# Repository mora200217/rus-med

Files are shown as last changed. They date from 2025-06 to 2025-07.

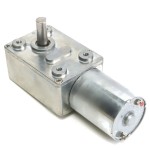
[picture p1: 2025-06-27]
sim/motor.jpeg

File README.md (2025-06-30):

# RUSMED
¡Conoce RUSMED! Una nueva herramienta para acelerar el proceso de diagnóstico de transtornos del manguito rotador 

---

## Sensores disponibles 
### IMU 
RUSMED cuenta con una unidad de medida inercial (IMU) BMI160. Publica la orientación del efector final. Esto permite una mayor escalabilidad del prototipo, al poder reconstruir el volumen analizado, a partir de la imagenes ultrasonográficas. 

### Integración con ROS2

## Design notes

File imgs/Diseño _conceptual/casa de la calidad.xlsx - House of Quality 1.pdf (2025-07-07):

Title: Sistema Robotizado para diagnóstico de TMR por US | Legend
Author: Grupo D | Θ | Strong Relationship | 9
Date: 27/4/2025 | Ο | Moderate Relationship | 3
Notes: | ▲ | Weak Relationship | 1
┼┼ | | | | | Strong Positive Correlation
┼ | Positive Correlation ▬ | Negative Correlation ▼ | Strong Negative Correlation ▼ | Objective Is To Minimize ▲ | Objective Is To Maximize
x | Objective Is To Hit Target
Column # | 1 | 2 | 3 | 4 | 5 | 6 | 7 | 8 | 9 | 10 | 11 | 12 | 13 | 14 | 15
Direction of Improvement: Minimize (▼), Maximize (▲), or Target (x) | ▼ | x | x | x | ▼ | ▲ | ▼ | x | ▲
| | | | Quality Characteristics (a.k.a. "Functional Requirements" or "Hows") Demanded Quality (a.k.a. "Customer Requirements" or "Whats")
1 | 9 | 26,3 | 10,0 | Rapidez en diagnóstico | Θ | ▲ | Ο | ▲ | ▲ | | | Ο | ▲
2 | 9 | 23,7 | 9,0 | Confiable | Θ | Ο | Θ | Θ | | | | Θ | Θ
3 | 9 | 15,8 | 6,0 | Agradable de usar | Ο | Θ | Ο | Θ | Θ | Ο | Ο | Ο
4 | 9 | 21,1 | 8,0 | Ligero para el paciente | | Ο | Θ | ▲ | Θ
5 | 3 | 13,2 | 5,0 | Fácil transporte | | ▲ | | | Ο

6

7

8

9

10

| | | | Target or Limit Value
| | | | Difficulty (0=Easy to Accomplish, 10=Extremely Difficult) | 8 | 4 | 9 | 9 | 7 | 4 | 5 | 8 | 10
| | | | Max Relationship Value in Column | 9 | 9 | 9 | 9 | 9 | 3 | 3 | 9 | 9
| | | | Weight / Importance | 497,4 | 315,8 | 528,9 | 402,6 | 397,4 | 47,4 | 47,4 | 339,5 | 239,5

Row #

Max Relationship Value in Row

Relative Weight

Weight / Importance

Tiempo de diagnóstico

Uso intuitivo de herramienta

### Ángulo de ataque transductor

Presión de contacto

Peso del Robot

Estética agradable

Ruido del mecanismo

Grado de autonomía ISO 8373

Repetibilidad

10 min
- 15 deg

1.5 - 2 kPa
50 N
- 30 dB

Nivel 3

SSIN - 0.8

Relative Weight | 17,7 | 11,2 | 18,8 | 14,3 | 14,1 | 1,7 | 1,7 | 12,1 | 8,5 | Powered by QFD Online (http://www.QFDOnline.com)

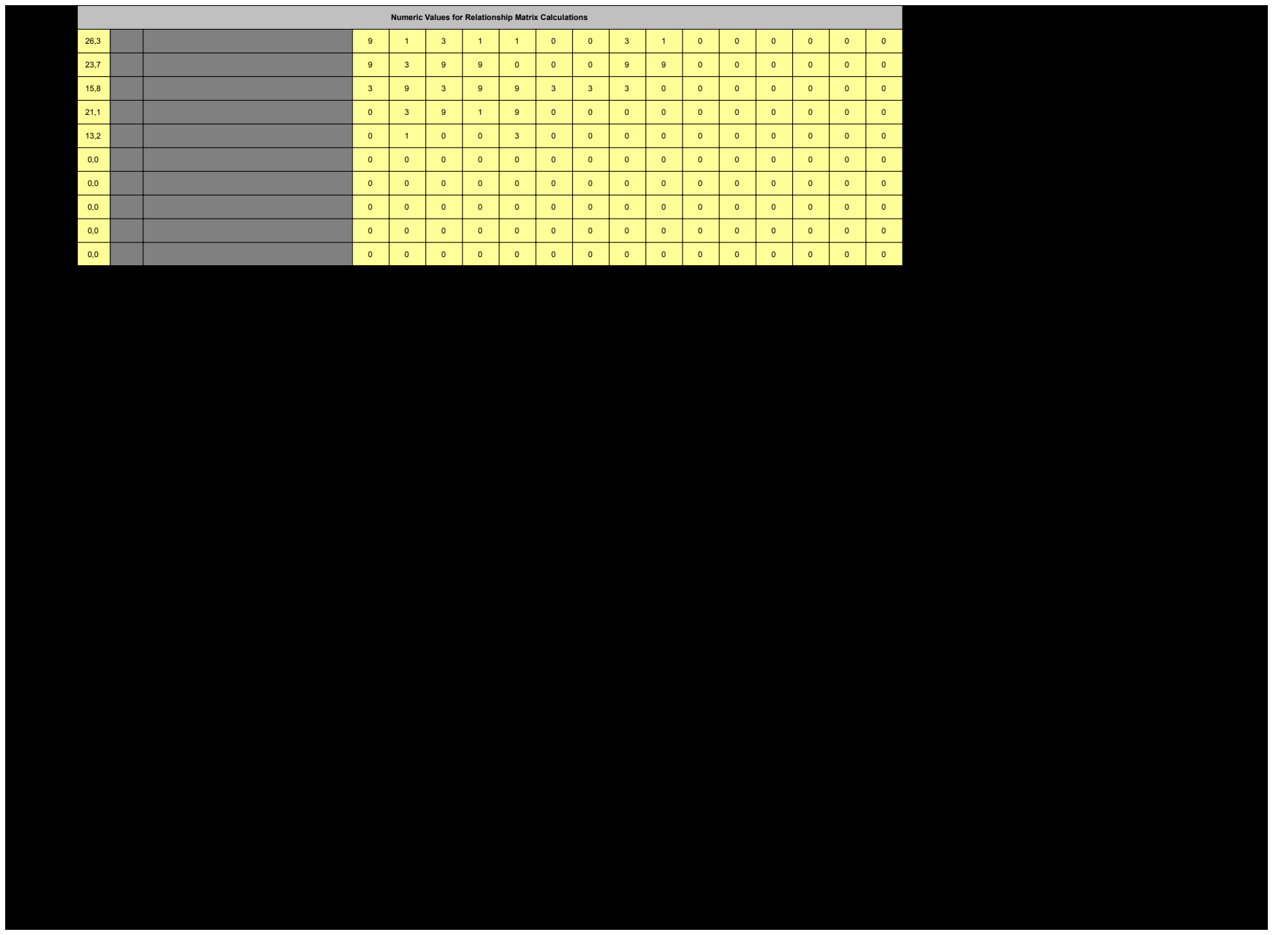
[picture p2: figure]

Numeric Values for Relationship Matrix Calculations

Chart Axis Values

0,95

0,85

0,75

0,65

0,55

0,45

0,35

0,25

0,15

0,05

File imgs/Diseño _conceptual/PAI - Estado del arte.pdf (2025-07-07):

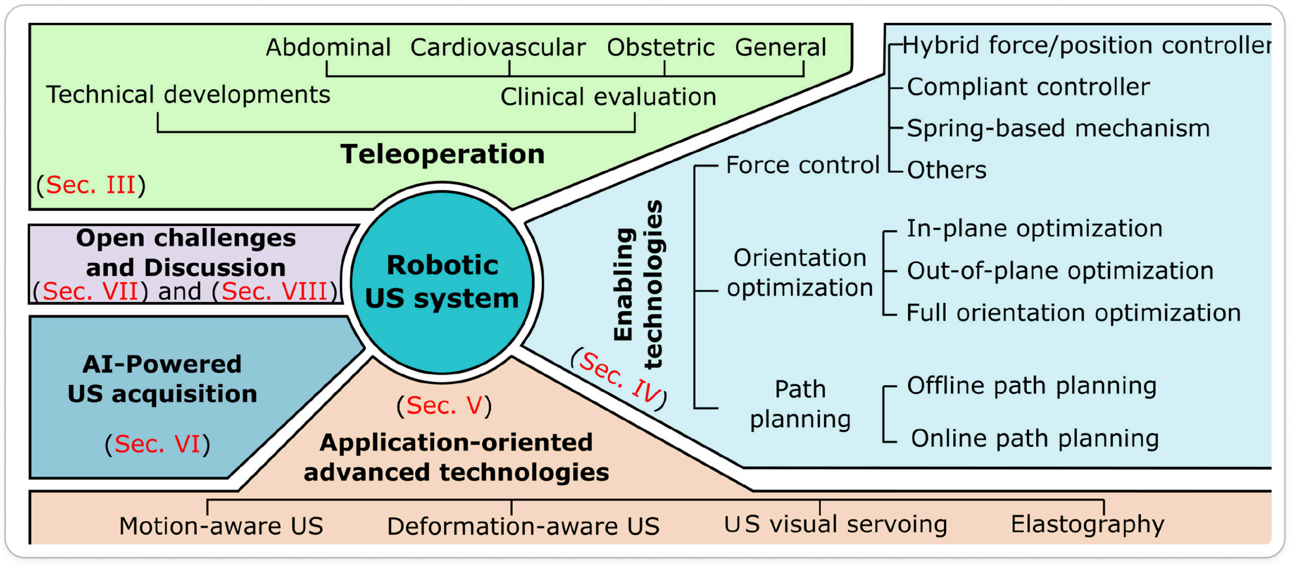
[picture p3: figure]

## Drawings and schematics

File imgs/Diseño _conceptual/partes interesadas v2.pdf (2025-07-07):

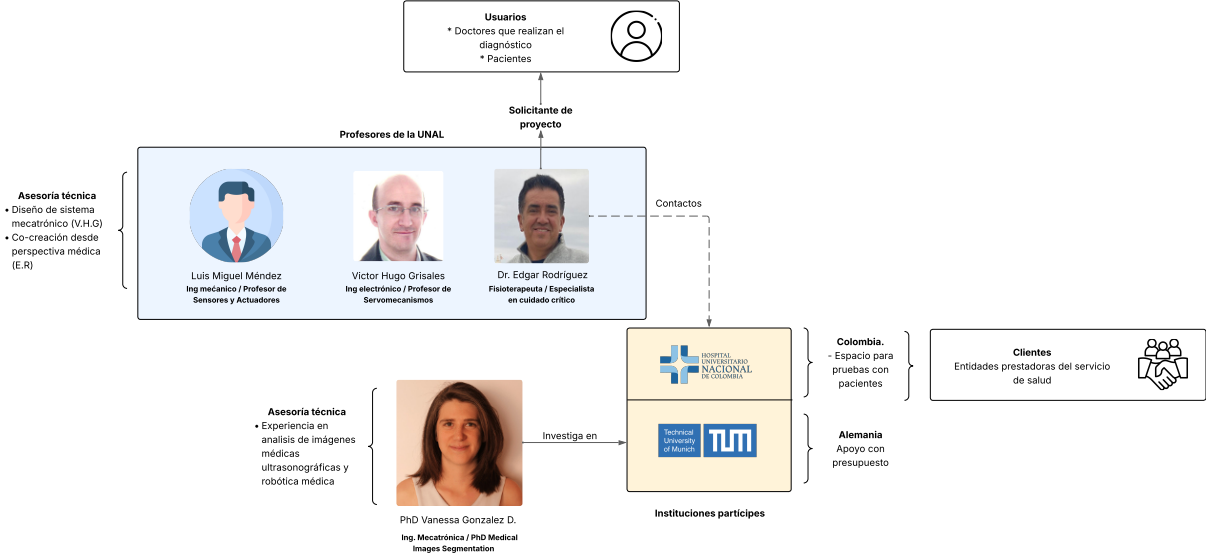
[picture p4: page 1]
Victor Hugo Grisales; Dr. Edgar Rodríguez; Solicitante de proyecto; Contactos; Colombia. - Espacio para pruebas con pacientes; Alemania Apoyo con presupuesto; Investiga en; Usuarios; Clientes; de salud

* Doctores que realizan el
diagnóstico
* Pacientes

Profesores de la UNAL

Asesoría técnica
- Diseño de sistema
mecatrónico (V.H.G)
- Co- creación desde
perspectiva médica

Luis Miguel Méndez
Ing me?anico / Profesor de
Sensores y Actuadores

Ing electrónico / Profesor de
Servomecanismos

Fisioterapeuta / Especialista
en cuidado crítico

Entidades prestadoras del servicio

- Experiencia en
analisis de imágenes
médicas
ultrasonográficas y
robótica médica

Instituciones partícipes PhD Vanessa Gonzalez D.

Ing. Mecatrónica / PhD Medical
Images Segmentation

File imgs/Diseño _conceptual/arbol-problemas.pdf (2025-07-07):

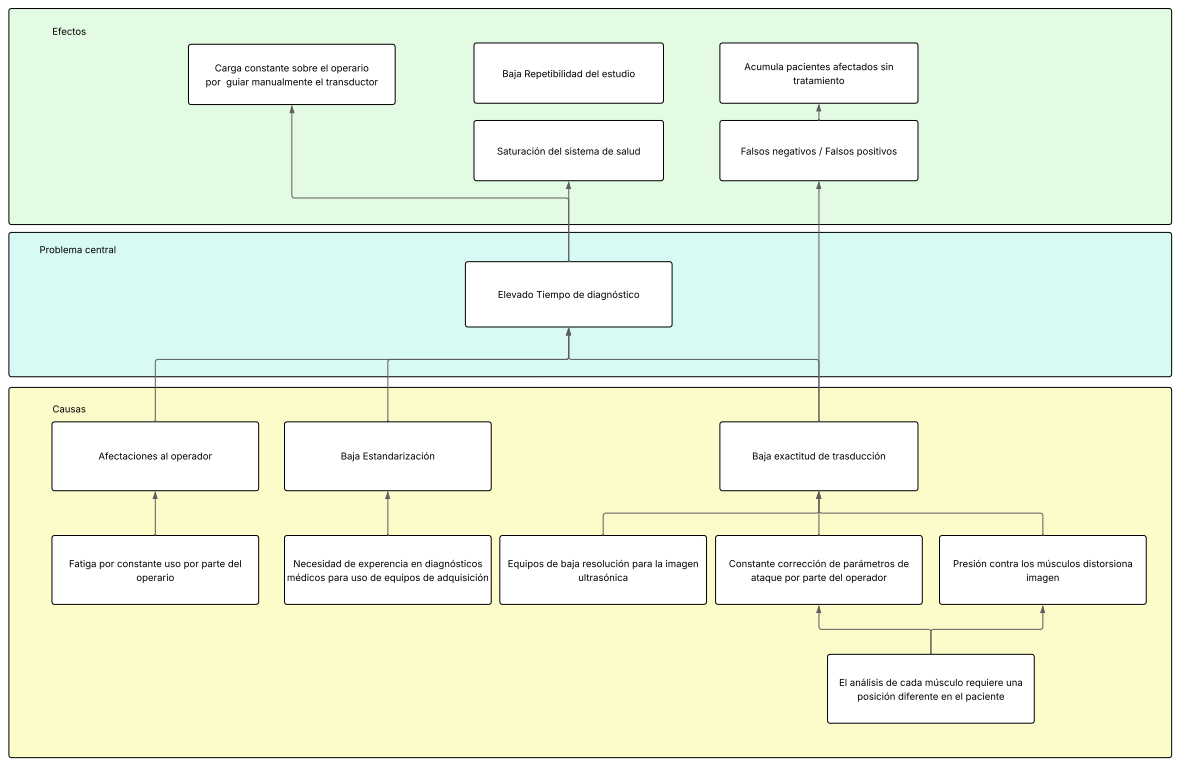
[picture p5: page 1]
Texto; imagen; ultrasónica; Saturación del sistema de salud; Falsos negativos / Falsos positivos; tratamiento; operario; Baja Estandarización; Efectos; Problema central; Causas

Carga constante sobre el operario
por guiar manualmente el transductor

Acumula pacientes afectados sin

Baja Repetibilidad del estudio

Elevado Tiempo de diagnóstico

Afectaciones al operador

Baja exactitud de trasducción

Fatiga por constante uso por parte del

Necesidad de experencia en diagnósticos
médicos para uso de equipos de adquisición

Equipos de baja resolución para la imagen

Constante corrección de parámetros de
ataque por parte del operador

Presión contra los músculos distorsiona

El análisis de cada músculo requiere una
posición diferente en el paciente

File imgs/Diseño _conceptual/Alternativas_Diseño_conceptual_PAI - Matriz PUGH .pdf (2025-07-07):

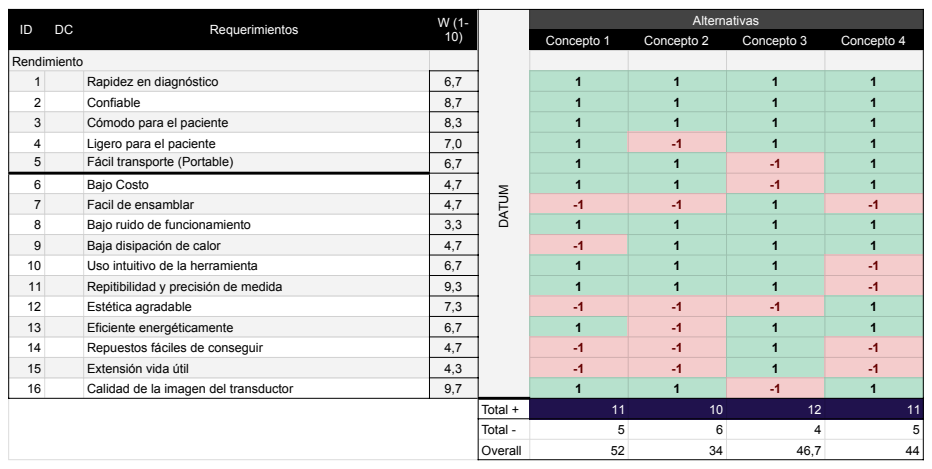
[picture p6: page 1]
Requerimientos; DATUM; Alternativas; Concepto 1; Concepto 2; Concepto 3; Concepto 4; Rendimiento; Rapidez en diagnóstico; Confiable; Cómodo para el paciente; Ligero para el paciente; Fácil transporte (Portable); Bajo Costo; Facil de ensamblar; Bajo ruido de funcionamiento; Baja disipación de calor; Uso intuitivo de la herramienta; Repitibilidad y precisión de medida; Estética agradable; Eficiente energéticamente; Repuestos fáciles de conseguir; Extensión vida útil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

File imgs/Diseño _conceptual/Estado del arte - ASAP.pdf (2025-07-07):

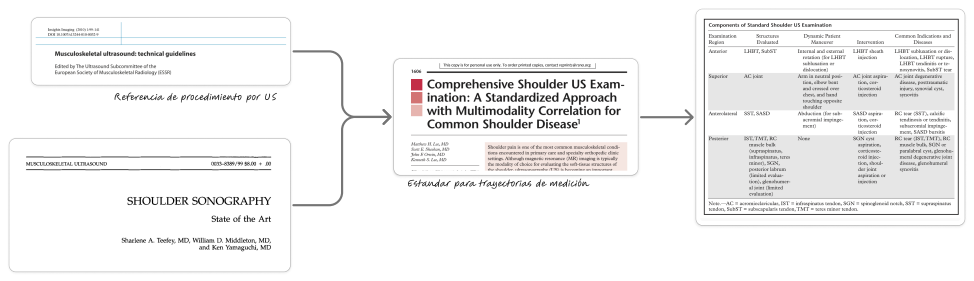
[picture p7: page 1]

Referencia de procedimiento por US

Estandar para trayectorias de medición

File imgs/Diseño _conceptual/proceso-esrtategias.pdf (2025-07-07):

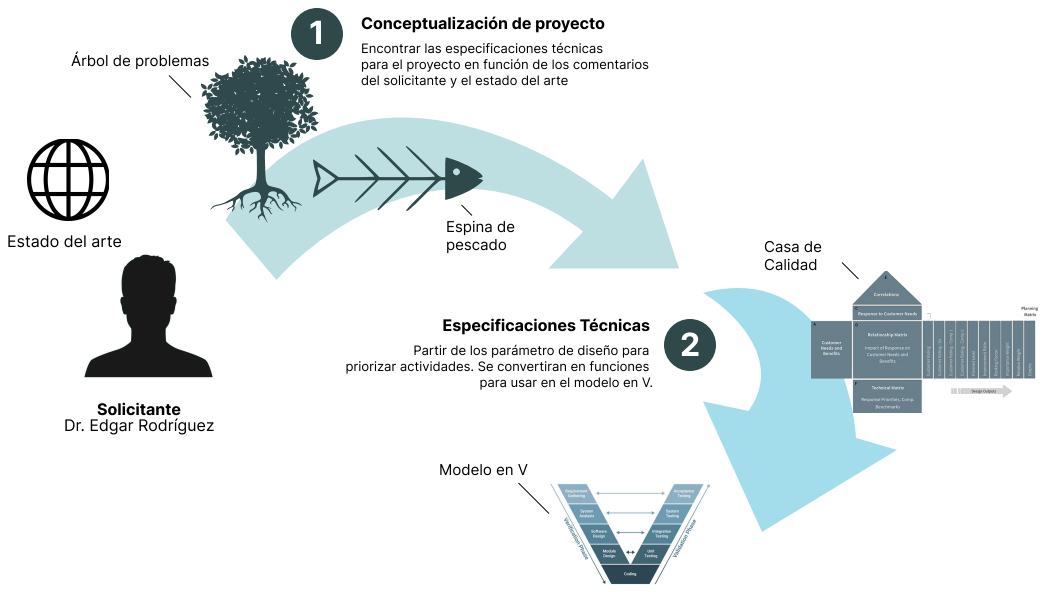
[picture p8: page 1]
Conceptualización de proyecto; 2 Especificaciones Técnicas; Espina de; pescado; Casa de; Calidad; Modelo en V

Encontrar las especificaciones técnicas
para el proyecto en función de los comentarios
del solicitante y el estado del arte

Árbol de problemas

Estado del arte

Partir de los parámetro de diseño para

priorizar actividades. Se convertiran en funciones

para usar en el modelo en V.

Solicitante Dr. Edgar Rodríguez

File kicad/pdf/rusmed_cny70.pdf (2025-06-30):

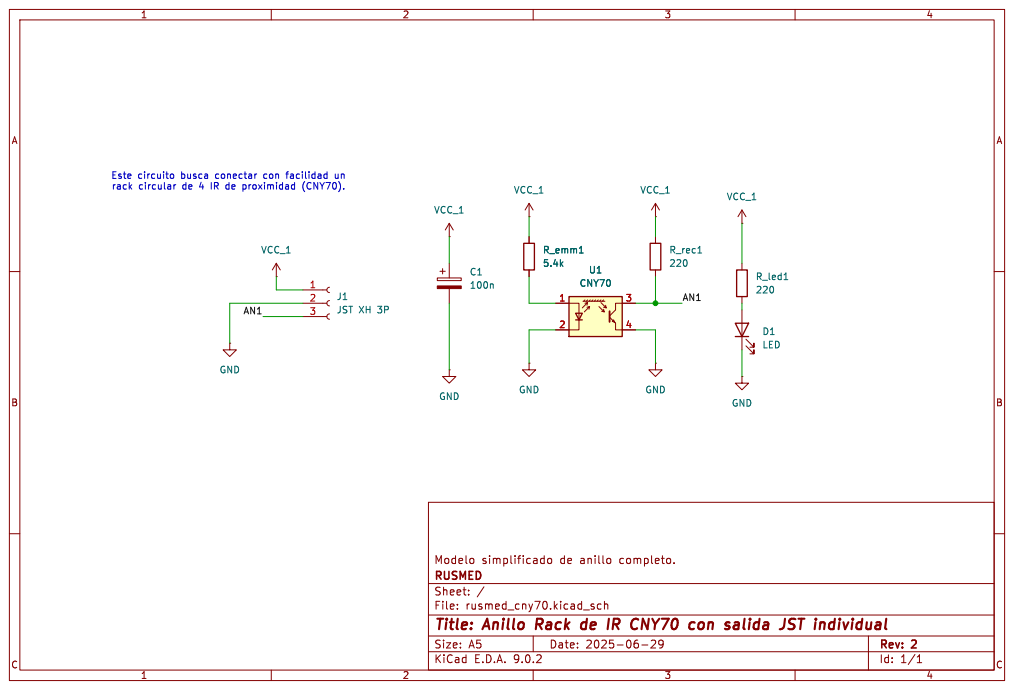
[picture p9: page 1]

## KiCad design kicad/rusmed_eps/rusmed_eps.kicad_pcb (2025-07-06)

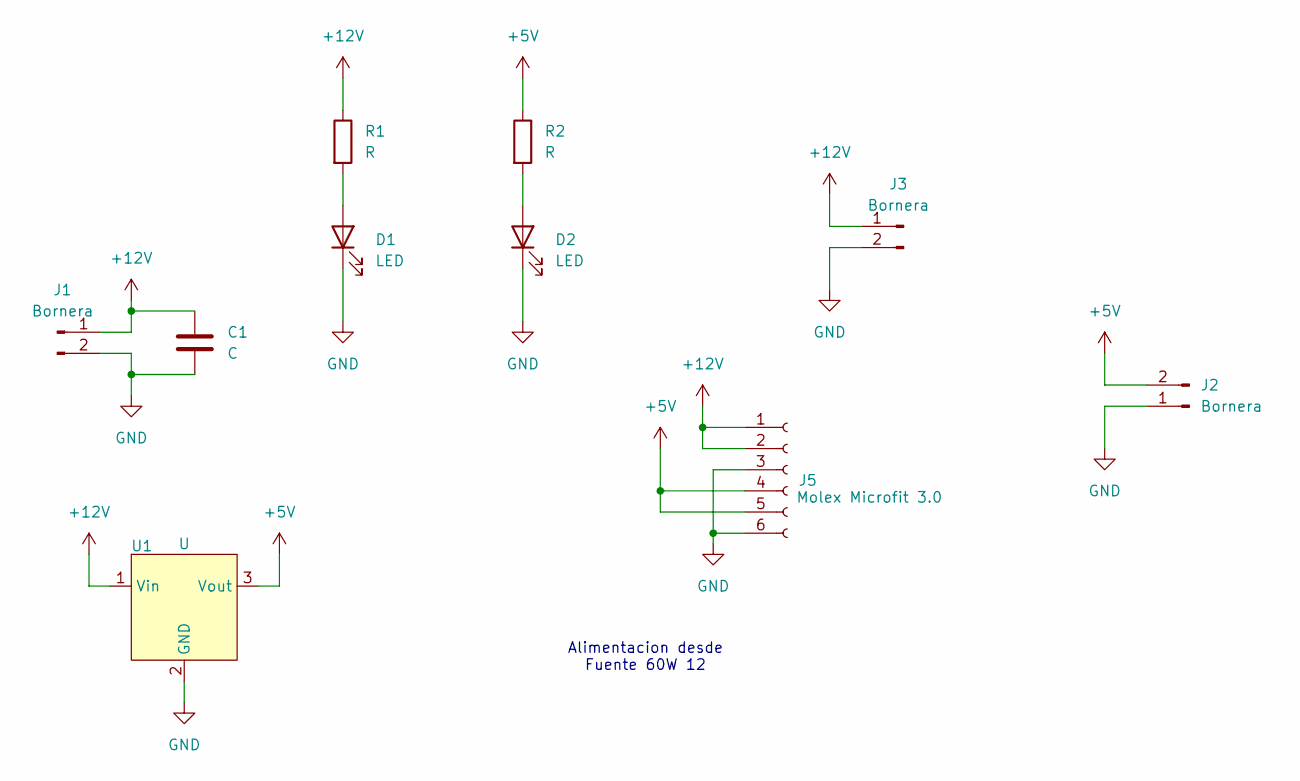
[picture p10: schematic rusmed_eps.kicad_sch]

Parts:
C1: C; C_Radial_D10.0mm_H16.0mm_P5.00mm
D1, D2: LED; LED_D5.0mm
J1, J2, J3: Bornera; TerminalBlock_Phoenix_MKDS-1,5-2_1x02_P5.00mm_Horizontal
J5: Molex Microfit 3.0; Molex_Micro-Fit_3.0_43045-0612_2x03_P3.00mm_Vertical
R1, R2: R; R_Axial_DIN0207_L6.3mm_D2.5mm_P10.16mm_Horizontal
U1: U; hw_0468

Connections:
+5V: J2.2, J5.4, J5.5, R2.1, U1.3 (Vout)
+12V: C1.1, J1.1, J3.1, J5.1, J5.2, R1.1, U1.1 (Vin)
GND: C1.2, D1.1 (K), D2.1 (K), J1.2, J2.1, J3.2, J5.3, J5.6, U1.2 (GND)
unnamed: D1.2 (A), R1.2
unnamed: D2.2 (A), R2.2

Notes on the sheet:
Alimentacion desde Fuente 60W 12

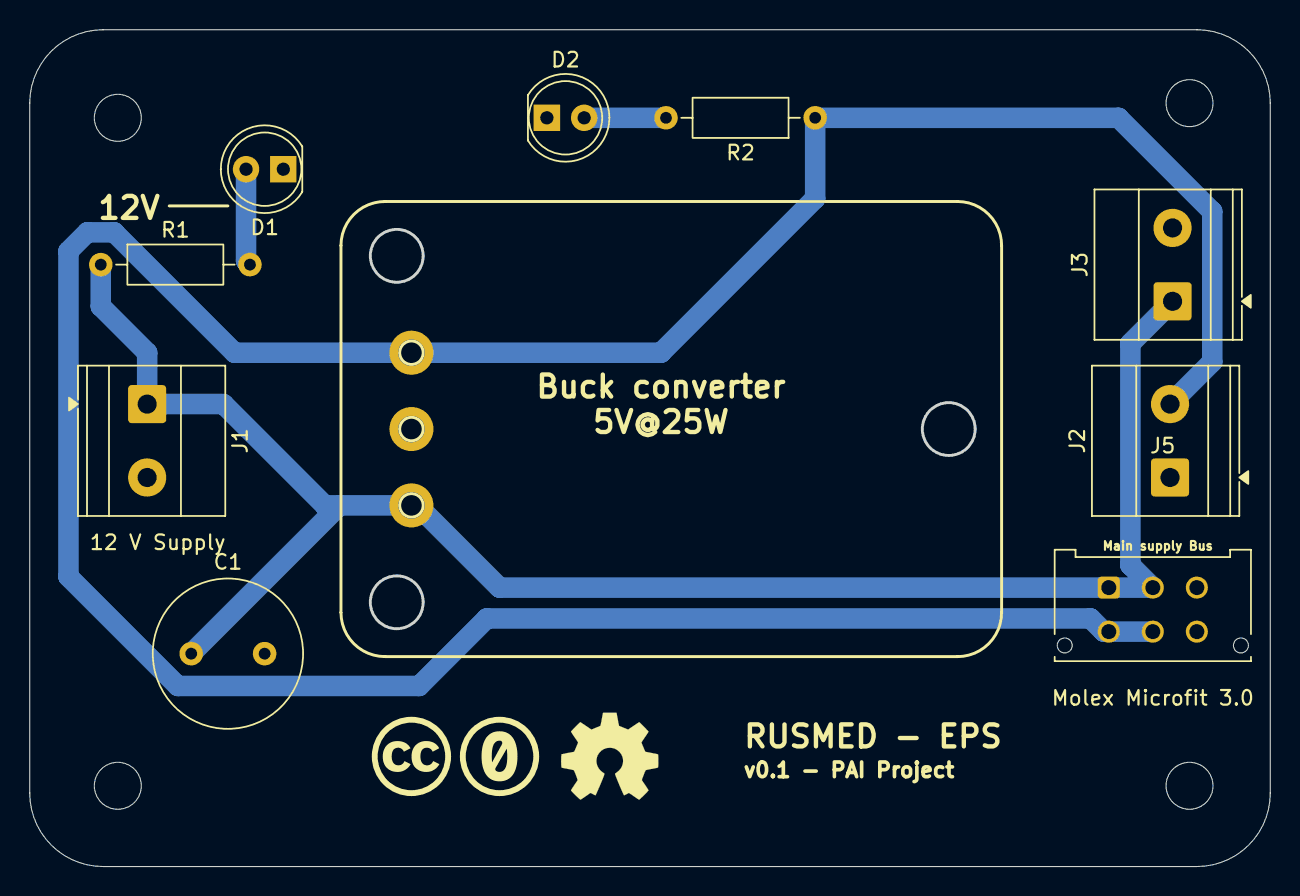
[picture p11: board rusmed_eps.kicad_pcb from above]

Board: 2 copper layers, 84.5 x 57.0 mm, 14 parts (0 on the bottom side), 5 nets.

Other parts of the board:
M1, M2, M3, M4: MountingHole_3.2mm_M3

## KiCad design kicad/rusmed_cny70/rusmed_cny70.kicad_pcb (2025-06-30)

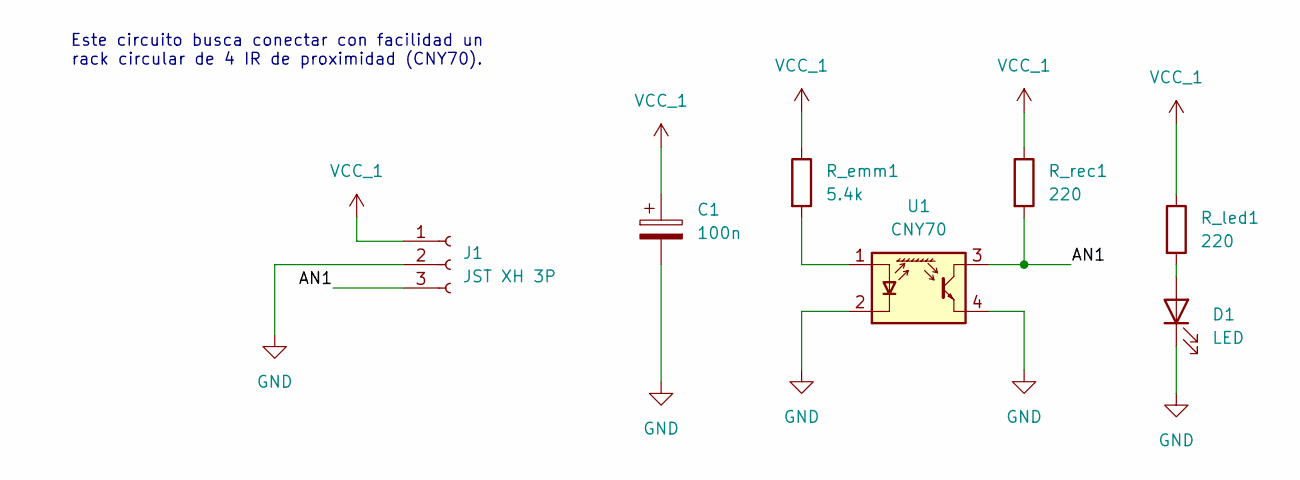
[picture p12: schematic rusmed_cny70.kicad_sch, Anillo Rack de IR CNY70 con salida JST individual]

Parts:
C1: 100n; CP_Elec_6.3x4.9
D1: LED; LED_1210_3225Metric_Pad1.42x2.65mm_HandSolder
J1: JST XH 3P; JST_XH_B3B-XH-A_1x03_P2.50mm_Vertical
R_emm1: 5.4k; R_1206_3216Metric
R_led1: 220; R_1206_3216Metric
R_rec1: 220; R_1206_3216Metric
U1: CNY70; Vishay_CNY70

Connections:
/AN1: J1.3, R_rec1.2, U1.3 (C)
GND: C1.2, D1.1 (K), J1.2, U1.2 (K), U1.4 (E)
unnamed: D1.2 (A), R_led1.2
unnamed: R_emm1.2, U1.1 (A)
VCC_1: C1.1, J1.1, R_emm1.1, R_led1.1, R_rec1.1

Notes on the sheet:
Este circuito busca conectar con facilidad un rack circular de 4 IR de proximidad (CNY70).

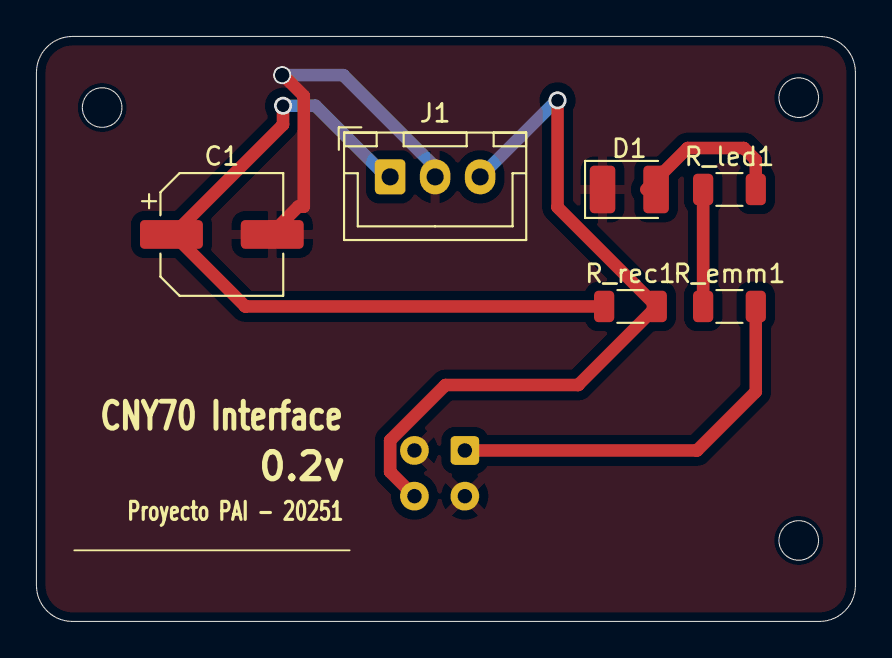
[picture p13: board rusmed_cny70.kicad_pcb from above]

Board: 2 copper layers, 45.5 x 32.5 mm, 7 parts (1 on the bottom side), 5 nets.

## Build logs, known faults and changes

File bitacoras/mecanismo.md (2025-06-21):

# Dimensionamiento de mecanismo 
Tomamos como referencia la expresión de fuerza de salida para el mecanismo completo. La fuerza constante está dada por la siguinete ecuación
$$
    F_{out} = k L_3\frac{L_1}{L_2}
$$

Donde $L_1$ es el avance del slider principal (stepper). La sensibilidad de transofmración depende de las dimensiones totales del sinfin($L_2$) Y la distancia entre los apoyos ($L_3$)

Sea $\gamma = \frac{L1}{L2}$ y representa el porcentaje de avance del slider controlado, respecto al alcance total. 

### Requisitos 
Usamos como valores iniciales, un rango de fuerza de $(1.2 - 20) ~N$. Por tanto, buscamos que un rango de avance $(0-100)%$ esté contenido dentro de dicho rango buscado. 

### Sensibilidad del sistema 
Tomemos la ecuación 

$$
    F_{out} = \left( k \gamma \right)~ L3 = S~L_3
$$

Donde $$S$$ es la sensiblidad del a fuerza de salida a la distancia de separación de los apoyos. Buscamos minimizar esta separación, en aras de compactar el sistema. Por tanto, buscamos un alta sensibilidad que permita el rango de fuerza para un valor de separación menos.

##### Resorte 
Analizando la sensibilidad S, 

$$ \frac{\partial S}{\partial k} = \gamma $$

Por tanto si buscamos un rango de operacion cercano a 0, aumentamos la robustez del sistema a los cambios de rigidez del resorte.

Se propuso un rango de 0.1 a 0.2 de avance, por lo que se tiene 

$$
    F_{out} = k ~ \left(0.1~~~~0.2 \right )~L_3
$$

Partimos de una distancia de 7 cm como supuesto inicial. Esto tomandolo como la mitad de la longitud del transductor, para tener una proporción estética. Para el resorte, partimos de $0.5 N/mm$. 
Validamos con el alcance 

$$ F_{out} =  \left(3.5, 7.0 \right) ~N$$

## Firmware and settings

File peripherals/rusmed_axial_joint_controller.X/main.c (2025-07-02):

/*
 * File:   main.c
 * Author: Andrés Morales Martínez 
 *
 * Created on June 26, 2025, 4:57 PM
 */

#include <xc.h>
#include <stdint.h>

#include "config_pic.h"
#include "stepper_controller.h"
#include "i2c_init_config.h"

// ==========================
// CONFIG BITS
// ==========================
#pragma config FOSC = INTOSC
#pragma config WDTE = OFF
#pragma config PWRTE = ON
#pragma config MCLRE = ON
#pragma config BOREN = OFF
#pragma config LVP = OFF

// ==========================
// DEFINES Y VARIABLES
// ==========================
#define DELAY_TIME 10 // ms

// Prototipos
void i2c_slave_init(void); 
void __interrupt() isr(void); 

// Pines:
// RB1: SDA1
// RB4: SCL1

volatile int pulses = 0; 
const float angle_per_pulse = 0.174f; 
volatile float theta = 0.0f; 

volatile int buff_ctl = 0; 
unsigned char* buffPtr; // Puntero para enviar buffer en I2C

volatile unsigned char flag = 0; 

// ==========================
// MAIN
// ==========================
void main(void) {
    // Configurar oscilador interno a 4 MHz
    OSCCON = 0b01100000;

    i2c_slave_init();  // Inicializar I2C en modo esclavo e interrupciones

    // Configurar interrupción externa INT0
    INTCONbits.INTE = 1; 
    INTCONbits.INTF = 0; 

    // Configurar pines como salida
    TRISAbits.TRISA3 = 0; 
    TRISAbits.TRISA4 = 0; 
    TRISAbits.TRISA1 = 0; 
    TRISBbits.TRISB3 = 0; 
    ANSELBbits.ANSB3 = 0; // Desactivar analógico en RB3

    // Señal de inicio: encender LEDs 1 s
    LATAbits.LATA1 = 1; 
    LATBbits.LATB3 = 1; 
    __delay_ms(1000); 
    LATAbits.LATA1 = 0; 
    LATBbits.LATB3 = 0; 

    while(1) {
        theta = ((float)pulses) * angle_per_pulse;

        LATAbits.LATA3 = flag; 
        LATAbits.LATA4 = ~flag; 

        // Espacio para PID en lazo cerrado
    }
}

// ==========================
// INTERRUPT SERVICE ROUTINE
// ==========================
void __interrupt() isr(void) {
    // INT0: Contador de pulsos
    if (INTCONbits.INTF) {
        pulses++; 
        LATBbits.LATB3 ^= 1; // Indicador de pulso
        INTCONbits.INTF = 0; // Limpiar flag
    }

    // I2C Slave
    if (SSP1IF && SSP1IE) {
        if (!SSP1STATbits.D_nA && !SSP1STATbits.R_nW) {
            // Dirección recibida
            volatile uint8_t dummy = SSP1BUF;
            buff_ctl = 0; 
        }
        else if (SSP1STATbits.D_nA && !SSP1STATbits.R_nW) {
            // Dato recibido
            int8_t data = (int8_t) SSP1BUF;
            if (data == 0x02) {
                flag = 0;
            } else if (data == 0x03) {
                flag = 1;
            }
            SSP1CON1bits.CKP = 1; // Reanudar reloj
        }
        else if (SSP1STATbits.R_nW) {
            // Master solicita lectura
            volatile uint8_t dummy = SSP1BUF;

            unsigned char* path = (unsigned char*)&theta; 
            SSP1BUF = *(path + buff_ctl);  
            buff_ctl = (buff_ctl + 1) % 4; 

            SSP1CON1bits.CKP = 1; // Reanudar reloj
        }

        SSP1IF = 0; // Limpiar flag
    }
}

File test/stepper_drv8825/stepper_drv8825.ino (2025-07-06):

// DRV8826 Stepper Test
// Connect STEP to pin 3
// Connect DIR  to pin 4
// Connect ENABLE to GND (or pin if you want to control it)

#define STEP_PIN 3
#define DIR_PIN 4

bool allow_movement = false;
bool dir_flag = true;

void setup() {
  pinMode(STEP_PIN, OUTPUT);
  pinMode(DIR_PIN, OUTPUT);

  digitalWrite(DIR_PIN, HIGH);  // Initial direction

  Serial.begin(9600);
}

void loop() {
  // UART check
  if (Serial.available()) {
    char read_val = Serial.read();
    
    if (read_val > 91) {
      switch (read_val) {
        case 'a':
          dir_flag = true;
          allow_movement = true;
          Serial.println("Movimiento izquierdo");
          break;
        case 'b':
          dir_flag = false;
          allow_movement = true;
          Serial.println("Movimiento derecho");
          break;
        default:
          allow_movement = false;
          Serial.println("Sin movimiento");
          break;
      }
    }

    digitalWrite(DIR_PIN, dir_flag ? HIGH : LOW);
  }

  if (allow_movement) {
    digitalWrite(STEP_PIN, HIGH);
    delayMicroseconds(500);  // adjust for speed
    digitalWrite(STEP_PIN, LOW);
    delayMicroseconds(500);
  }
}

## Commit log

2025-06-05 [Update] Proteccion de polaridad
2025-06-27 [New] MplabX project. Agregado proyecto de prueba de I2C para PIC16F1827. Protocolo creado y configurado periferico (PIC) como esclavo. Se hace la prueba con arduino satisfactoriamente. No tiene lazo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
2025-06-27 [Update] Control Law Simscape modelado de lazo de control axial.
2025-06-30 [New] Images for archive. Rusmed pcb design
2025-06-30 [New] Mplab files. I2C added for PIC16F1827. Basic encoder conter added. Basic Pulse Important to notice that the tests for the PIC to control the stepper, is with a LED. Just noticing if it can be u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
2025-06-30 [New] RUSMED cny70 pcb. With Schematic
    [rusmed_cny70.kicad_pcb, rusmed_cny70.kicad_sch]
2025-06-30 [New] Simulink simulation for control loop in axial joint.
    It takes the basic model of a DC motor an a first approx to the close loop model. It need to me updated
    with the real DC motor properties. The encoder model (discrete) works without direction
2025-06-30 [Delete] DS_store clean
    [rusmed_eps_board.kicad_pcb, rusmed_eps_board.kicad_sch]
2025-06-30 [New] rusmed_eps system. Basic connectors added. No HW-468. Pending
    [onecorner_EPS.kicad_pcb, onecorner_EPS.kicad_sch, rusmed_eps.kicad_pcb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]
2025-07-02 [Update] Change format. Organize info in mplabx and clean project. More readable structure.
    It still works in this manner:
    - PIC sends angle position from encoder in Little Endian from ros2control HW interface (Broadcaster)
    - Waits for a command (If 0x02 it moves the DC motor left. And 0x03 Right)
2025-07-06 [Update] test
    [rusmed_eps.kicad_pcb, rusmed_eps.kicad_sch]
2025-07-06 [Update] test code in arduino for DRV8825
2025-07-07 [New] Docker compose information
    [rusmed_eps.kicad_sch]
